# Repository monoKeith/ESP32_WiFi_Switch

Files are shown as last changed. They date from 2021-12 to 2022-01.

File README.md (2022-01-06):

# ESP32_WiFi_Switch

This project include hardware design and firmware implementation for a ESP32-S2 powered network accessable on/off switch.

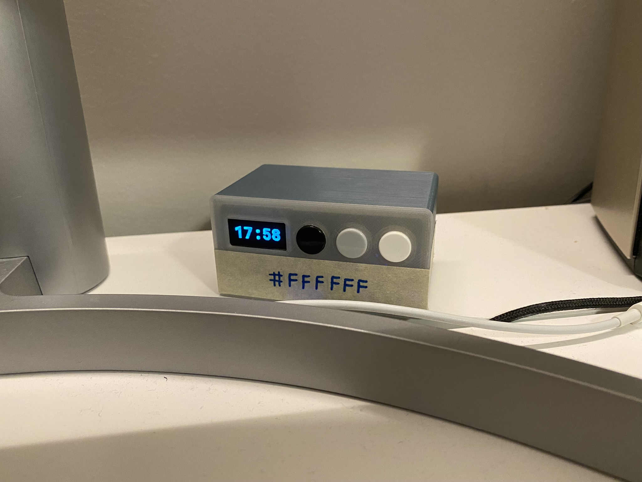
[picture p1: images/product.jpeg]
product


This switch have an 128*64 OLED I2C display to show information. User can turn on/off the switch from HomeKit, physical button, or web interface.

Powered by a [ESP32-S2-Wroom](https://www.espressif.com/sites/default/files/documentation/esp32-s2-wroom_esp32-s2-wroom-i_datasheet_en.pdf). Because the use of ESP32-S2 specific hardware timer library, firmware might have compatibility issue on older (or different) ESP32 models.

## Hardware

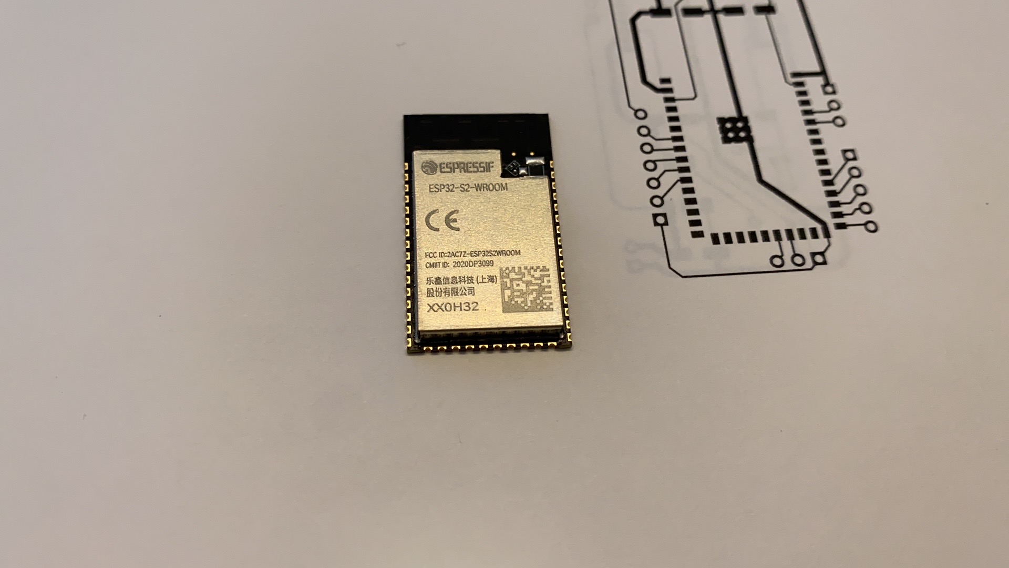
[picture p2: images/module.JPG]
ESP32-S2 Module


PCB printed | PCB etched
:-------------------------:|:-------------------------:
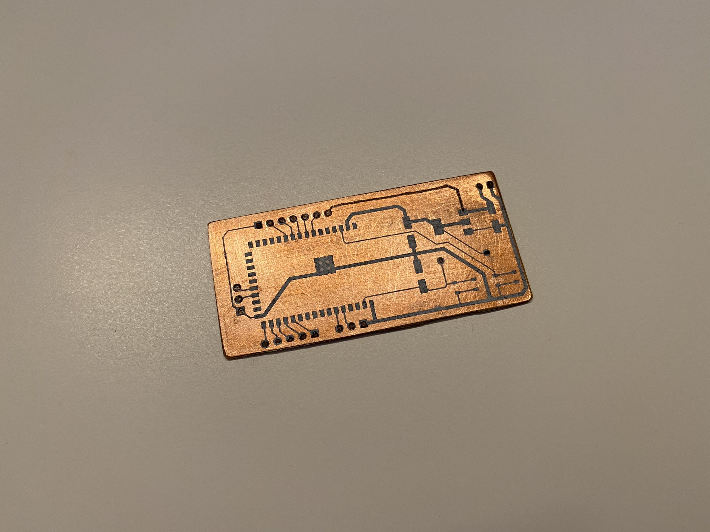
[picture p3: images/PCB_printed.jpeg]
PCB printed
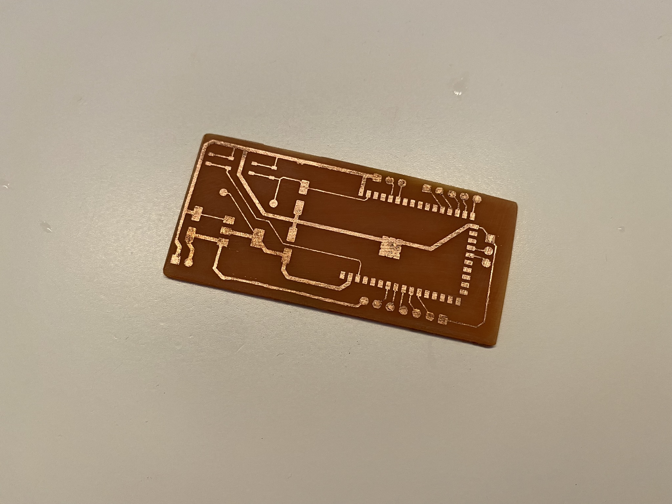
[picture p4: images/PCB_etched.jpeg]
PCB etched
 | 

Soldered | Bread board
:-------------------------:|:-------------------------:
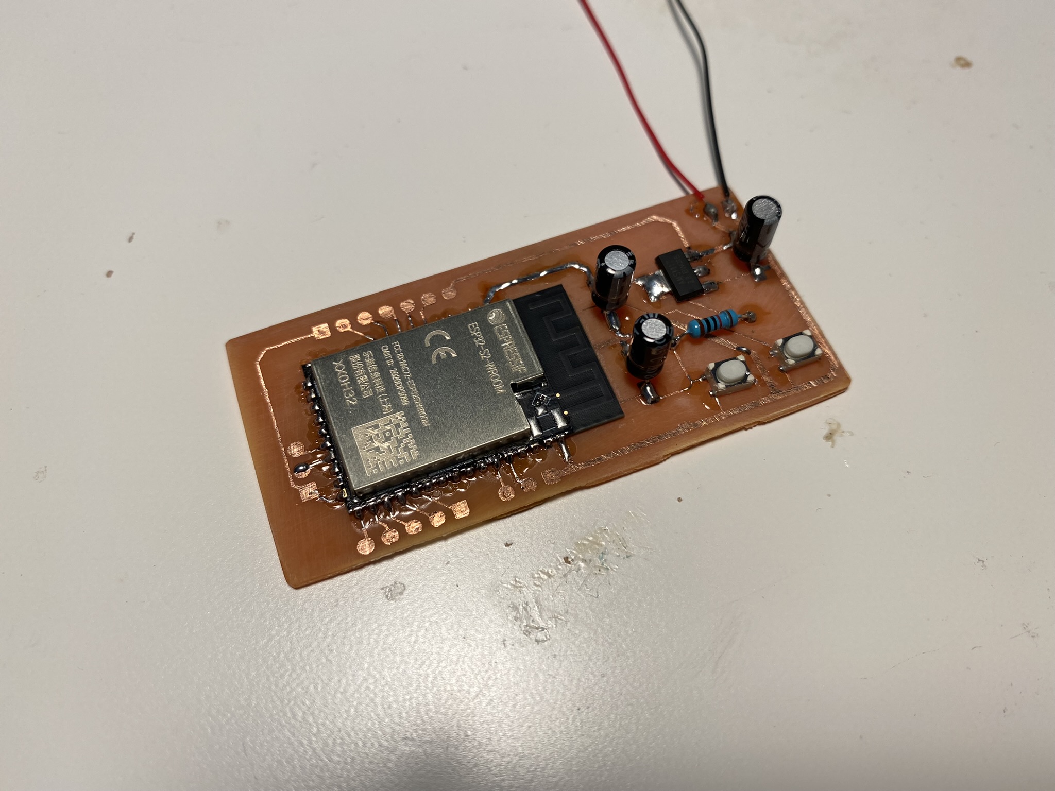
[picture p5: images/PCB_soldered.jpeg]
PCB soldered
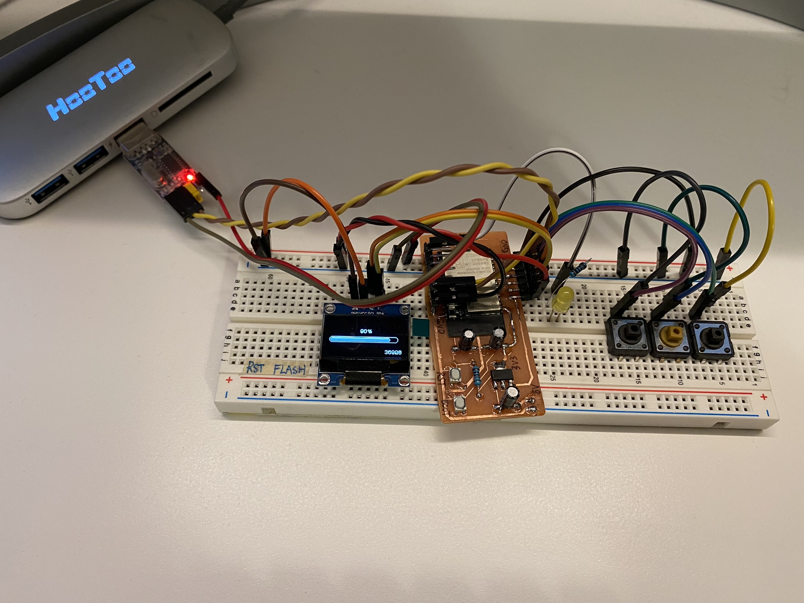
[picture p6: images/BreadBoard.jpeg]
Breadbord
 | 

Single layer PCB designed with [KiCad](https://www.kicad.org/) in `./breakout_board`. This is only useful for starting with only a [module](https://www.espressif.com/en/products/modules), unnecessary if you already have a dev board. Requires ESP32-S2-WROOM library from [this](https://github.com/eggsampler/ESP32-S2-Breakout) breakout board design.

Connected devices includes:

* 3 buttons pull-down to ground (resistors are optional)

* 1 mono-color 128*64 OLED I2C display [like this one](https://www.adafruit.com/product/326) (These are like $2 - $3 each on Aliexpress)

* external circuit to drive a relay (or MOSFET) from a GPIO pin. (I use a transistor to drive a 5V relay)

## Firmware

Firmware was implemented in C++ using PlatformIO arduino framework. Each part of the firmware is run a task of FreeRTOS. PlatformIO was initialized with [adafruit MagTag](https://www.adafruit.com/product/4800) configuration (which uses the same module), because ESP32-S2 Dev Board does not offer support for arduino framework.

Configure properties of firmware in `Firmware/src/config.h` according to how hardwares are connectred, and Wi-Fi credential. (ESP32-S2 allows any 2 GPIO pins to run I2C, connecting I2C display to any 2 GPIO pins should work)

### Functionalities

* [Automatically connect to Wi-Fi](https://randomnerdtutorials.com/esp32-useful-wi-fi-functions-arduino/) with credentials configured in `config.h`

* [Get current time from time server](https://randomnerdtutorials.com/esp32-date-time-ntp-client-server-arduino/)

* Sync time with time server periodically (uses [ESP32-S2 hardware timer](https://github.com/khoih-prog/ESP32TimerInterrupt/blob/master/examples/TimerInterruptTest/TimerInterruptTest.ino))

* [Turn on / off the switch from web interface](https://randomnerdtutorials.com/esp32-web-server-arduino-ide/)

* Turn on / off the switch with buttons, (white = on, gray = off)

* Press black button to cycle through display mode [REGULAR] -> [DEBUG] -> [OFF]

* Show message on screen when switch is being turn on / off, message stay on screen for 3000ms by default (configurable in `config.h`)

### Display

[REGULAR] mode:

* only shows current time

* display message in full screen if any.

[DEBUG] mode:

* on / off status of the switch

* current time

* Wi-Fi connection status, IP address and RSSI

* display message if any, otherwise show the time of last clock synchronization.

* time mark in ms for current message to hit it's 3000ms lifetime

* uptime in ms

REGULAR | REGULAR-MESSAGE| DEBUG
:-------------------------:|:-------------------------:|:-------------------------:
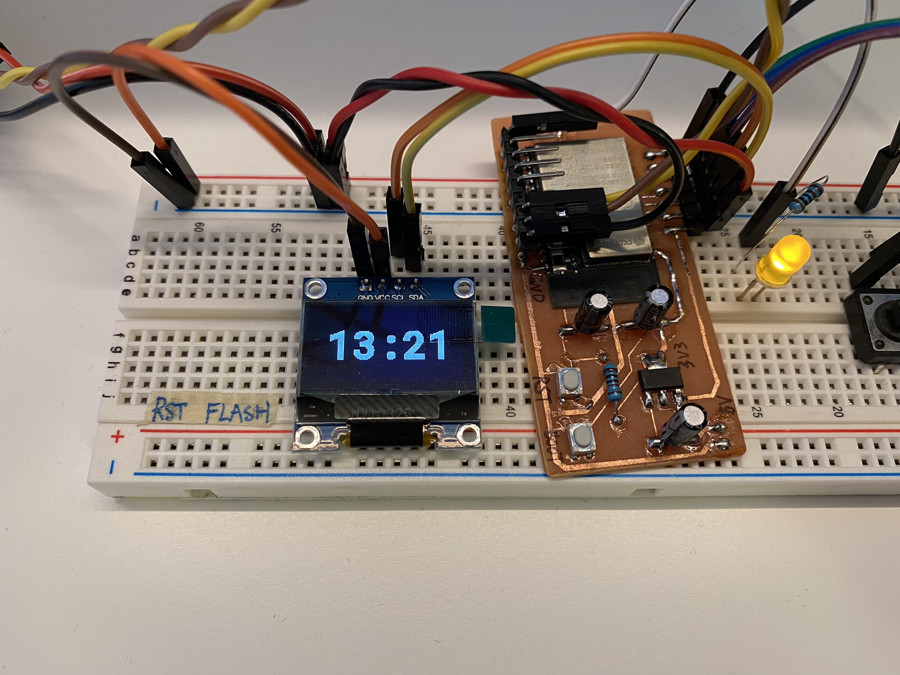
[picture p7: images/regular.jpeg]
regular
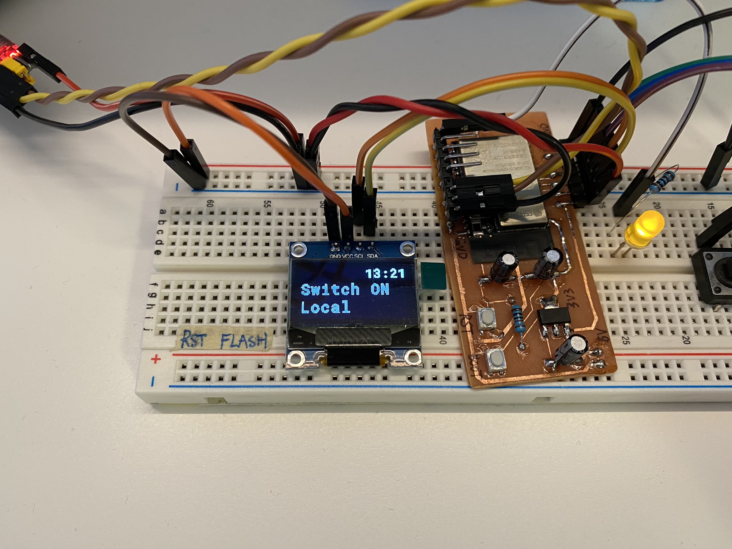
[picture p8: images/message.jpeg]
message
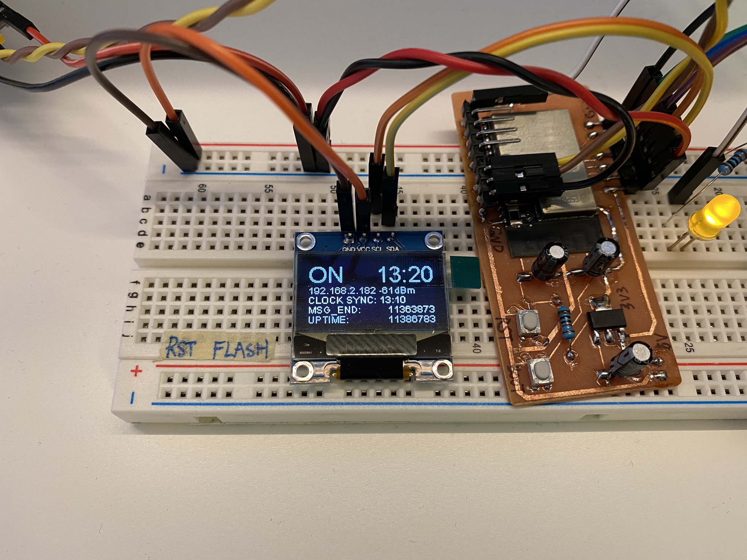
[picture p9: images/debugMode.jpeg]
debug
 |  | 

### PlatformIO Libraries

* [esp8266-oled-ssd1306](https://github.com/ThingPulse/esp8266-oled-ssd1306)

* [ESP32TimerInterrupt](https://github.com/khoih-prog/ESP32TimerInterrupt)

* [ESPAsyncWebServer](https://github.com/me-no-dev/ESPAsyncWebServer/)

### HomeBridge Plugin

To make the switch accessable from [iOS Home](https://www.apple.com/ca/ios/home/), a separate [HomeBridge](https://homebridge.io/) server is required. I am running the HomeBridge server on a [RaspberryPi Zero W](https://www.raspberrypi.com/products/raspberry-pi-zero-w/).

Install this plugin: [homebridge-http-switch](https://github.com/Supereg/homebridge-http-switch#readme) in HomeBridge, change settings (fill in the ip address and name):

```
{
    "accessory": "HTTP-SWITCH",
    "name": "<name-display-in-Home>",
    "switchType": "stateful",
    "serialNumber": "<fill-in-anything-here>",
    "onUrl": "http://<ip-of-esp32>:80/homebridge/switch/on",
    "offUrl": "http://<ip-of-esp32>:80/homebridge/switch/off",
    "statusUrl": "http://<ip-of-esp32>:80/homebridge/switch/status"
}
```

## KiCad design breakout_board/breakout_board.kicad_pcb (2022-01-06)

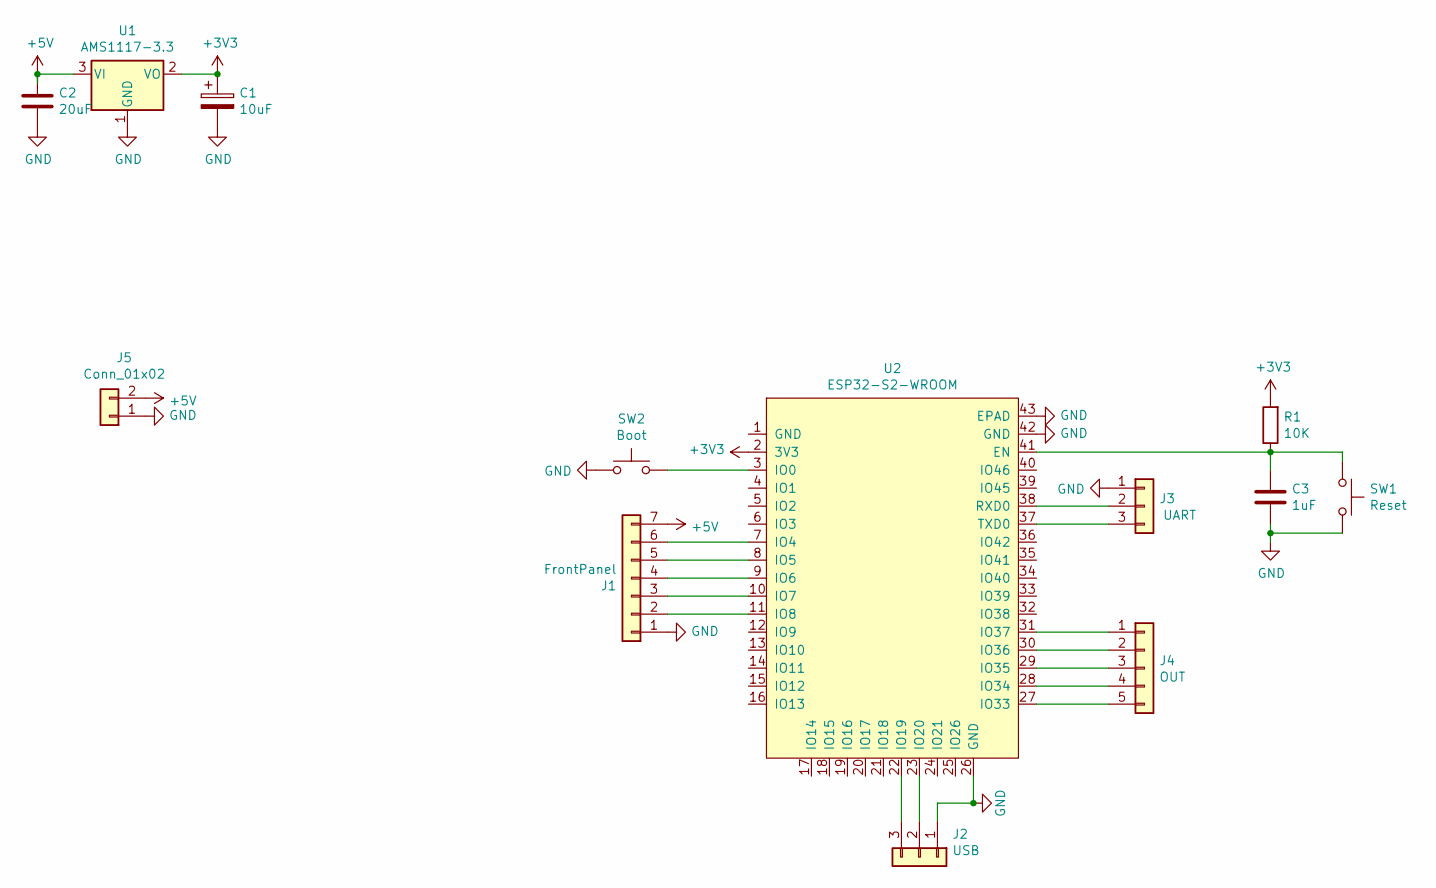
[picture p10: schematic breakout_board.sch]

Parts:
C1: 10uF; CP_Elec_5x5.9
C2: 20uF; CP_Elec_5x5.9
C3: 1uF; CP_Elec_5x5.9
J1: FrontPanel; PinHeader_1x07_P2.54mm_Vertical
J2: USB; PinHeader_1x03_P2.54mm_Vertical
J3: UART; PinHeader_1x03_P2.54mm_Vertical
J4: OUT; PinHeader_1x05_P2.54mm_Vertical
J5: Conn_01x02; PinHeader_1x02_P2.54mm_Vertical
R1: 10K; R_Axial_DIN0207_L6.3mm_D2.5mm_P10.16mm_Horizontal
SW1: Reset; SW_Push_1P1T_NO_Vertical_Wuerth_434133025816
SW2: Boot; SW_Push_1P1T_NO_Vertical_Wuerth_434133025816
U1: AMS1117-3.3; SOT-223-3_TabPin2
U2: ESP32-S2-WROOM

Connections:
+3V3: C1.1, R1.2, U1.2 (VO), U2.2 (3V3)
+5V: C2.1, J1.7, J5.2, U1.3 (VI)
GND: C1.2, C2.2, C3.2, J1.1, J2.1, J3.1, J5.1, SW1.2, SW2.1, U1.1 (GND), U2.26 (GND), U2.42 (GND), U2.43 (EPAD)
unnamed: C3.1, R1.1, SW1.1, U2.41 (EN)
unnamed: J1.2, U2.11 (IO8)
unnamed: J1.3, U2.10 (IO7)
unnamed: J1.4, U2.9 (IO6)
unnamed: J1.5, U2.8 (IO5)
unnamed: J1.6, U2.7 (IO4)
unnamed: J2.2, U2.23 (IO20)
unnamed: J2.3, U2.22 (IO19)
unnamed: J3.2, U2.38 (RXD0)
unnamed: J3.3, U2.37 (TXD0)
unnamed: J4.1, U2.31 (IO37)
unnamed: J4.2, U2.30 (IO36)
unnamed: J4.3, U2.29 (IO35)
unnamed: J4.4, U2.28 (IO34)
unnamed: J4.5, U2.27 (IO33)
unnamed: SW2.2, U2.3 (IO0)

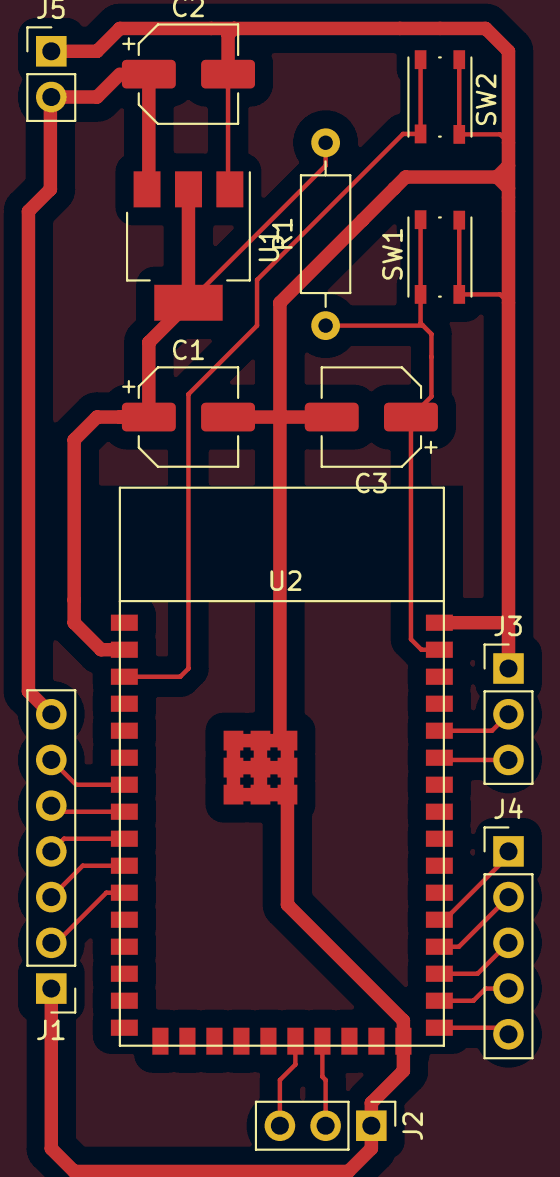
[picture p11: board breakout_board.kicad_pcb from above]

Board: 2 copper layers, 13 parts (0 on the bottom side), 19 nets.

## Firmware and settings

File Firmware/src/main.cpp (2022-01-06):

#include <Arduino.h>
#include "config.h"
#include "state.h"
#include "monitor.h"
#include "ioControl.h"
#include "server.h"
#include "clockControl.h"

// Stack sizes
#define STACK_SIZE_SMALL 32768
#define STACK_SIZE_TINY 16384

void connectionWatch(void *pvParameters)
{
    // https://randomnerdtutorials.com/esp32-useful-wi-fi-functions-arduino/
    while (true)
    {
        if (state::wirelessConnected)
        {
            // Check again in 5s
            delay(5000);
            continue;
        }

        // Setup connection
        WiFi.disconnect();
        WiFi.mode(WIFI_STA);
        WiFi.begin(ssid, password);

        unsigned long startAttemptTime = millis();

        while (!state::wirelessConnected && (millis() - startAttemptTime < WIFI_TIMEOUT_MS))
        {
            delay(500);
        }
    }
}

void monitorThread(void *pvParameters)
{
    // Initialize display
    // TODO: show boot screen
    monitor::setup();

    while (true)
    {
        // Delay for 50ms, ~14 fps
        delay(50);
        // Refresh monitor, takes about 20ms?
        monitor::refresh();
    }
}

void ioThread(void *pvParameters)
{
    while (true)
    {
        // Delay for 100ms
        delay(100);
        // Refresh IO
        ioControl::refresh();
    }
}

// Arduino Initialize
void setup()
{
    // Setup WiFi connection watchdog
    xTaskCreatePinnedToCore(connectionWatch,
                            "ConnectionThread",
                            STACK_SIZE_TINY,
                            NULL,
                            5,
                            NULL,
                            CONFIG_ARDUINO_RUN_CORE0);

    // Setup display
    xTaskCreate(monitorThread,
                "MonitorThread",
                STACK_SIZE_SMALL,
                NULL,
                2,
                NULL);

    // Setup clock
    clockControl::setup();

    // Setup web server
    server::setup();

    // Setup GPIO interrupt (for buttons)
    ioControl::setup();
    xTaskCreate(ioThread,
                "IoThread",
                STACK_SIZE_TINY,
                NULL,
                1,
                NULL);
}

// Arduino run loop
void loop()
{
    // Update WiFi status
    state::wirelessConnected = (WiFi.status() == WL_CONNECTED);
    if (state::wirelessConnected)
    {
        // Update local IP and RSSI
        state::localIP = WiFi.localIP().toString();
        state::wirelessRSSI = String(WiFi.RSSI()) + "dBm";
    }

    // Update clock, clock control cannot run as a Task?
    clockControl::update();

    // Done
    delay(500);
}

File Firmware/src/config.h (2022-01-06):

#ifndef CONFIG_H
#define CONFIG_H

/* WiFi credentials */
static const char *ssid = "YOUR_SSID";
static const char *password = "YOUR_PASSWD";
#define WIFI_TIMEOUT_MS 30000

/* GPIO Pins */

#define SDA_PIN 4
#define SCL_PIN 5

#define WHITE_BUTTON_PIN 6
#define GRAY_BUTTON_PIN 7
#define BLACK_BUTTON_PIN 8

#define SWITCH_PIN 33

/* Display */

// Shift UI in regular screen, positive = down, negative = up
#define SCREEN_Y_OFFSET 7

// How long should a message (light on / off) stay on display?
#define MSG_DISPLAY_MS 3000

/* Time server */

#define NTP_SERVER "pool.ntp.org"

// Eastern time (-5 * 3600)
#define GMT_OFFSET_S -18000
#define DAYLIGHT_OFFSET_S 3600

// Update time periodically (30 mins)
#define TIME_SYNC_INTERVAL_MINUTES 30
// 2 mins for test
// #define TIME_SYNC_INTERVAL_MINUTES 2


/* HTTP server */

#define HTTP_TIMEOUT_MS 1000

#endif

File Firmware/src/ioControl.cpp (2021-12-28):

#include "ioControl.h"

namespace ioControl
{
    // Initialize interruption
    void setup()
    {
        // White
        pinMode(WHITE_BUTTON_PIN, INPUT_PULLUP);
        attachInterrupt(WHITE_BUTTON_PIN, white, FALLING);
        // Gray
        pinMode(GRAY_BUTTON_PIN, INPUT_PULLUP);
        attachInterrupt(GRAY_BUTTON_PIN, gray, FALLING);
        // Black
        pinMode(BLACK_BUTTON_PIN, INPUT_PULLUP);
        attachInterrupt(BLACK_BUTTON_PIN, black, FALLING);

        // Output pin
        pinMode(SWITCH_PIN, OUTPUT);
    }

    /* Button Press Callback functions */

    void white()
    {
        state::newMessage("Switch ON Local");
        state::switchOn = true;
    }

    void gray()
    {
        state::newMessage("Switch OFF Local");
        state::switchOn = false;
    }

    void black()
    {
        switch (state::displayMode)
        {
        case state::DisplayMode::REGULAR:
            state::displayMode = state::DisplayMode::DEBUG;
            break;

        case state::DisplayMode::DEBUG:
            state::displayMode = state::DisplayMode::OFF;
            break;

        default:
            state::displayMode = state::DisplayMode::REGULAR;
            break;
        }
    }

    /* IO output control */

    void refresh()
    {
        // switch
        digitalWrite(SWITCH_PIN, state::switchOn ? HIGH : LOW);
    }
}

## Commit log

2021-12-26 Breakout board design, Initialize PIO project
    [breakout_board.kicad_pcb, breakout_board.sch]
2021-12-26 Change PIO project to Arduino framework
2021-12-26 Separate I2C display to a new Monitor class
2021-12-27 Replace State class with state namespace
    [config.h, main.cpp]
2021-12-27 Switch ON/OFF from button press
2021-12-27 HTTP control with Web UI
    [breakout_board.sch]
2022-01-04 New breakout board design
    [breakout_board.kicad_pcb]
2022-01-06 Fix bug: clock doesn't run
    [config.h, main.cpp]
